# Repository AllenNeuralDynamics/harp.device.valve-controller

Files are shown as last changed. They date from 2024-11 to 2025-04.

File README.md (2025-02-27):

A Harp-compliant, 16-channel MOSFET Output board for valve control.

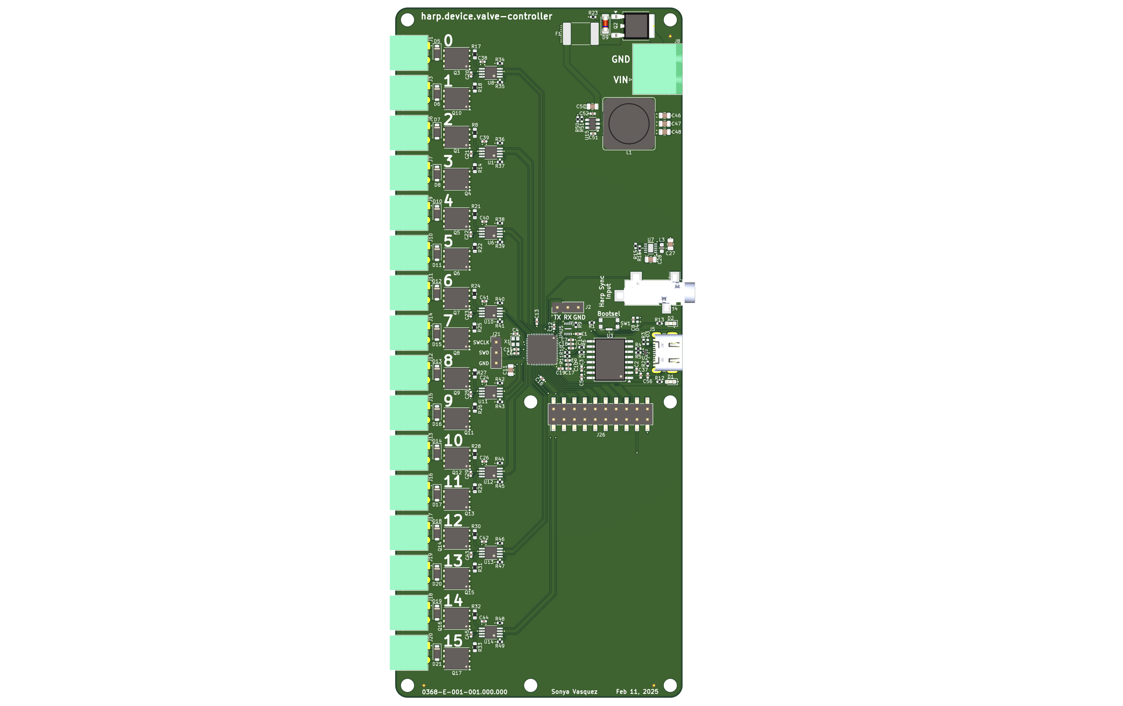
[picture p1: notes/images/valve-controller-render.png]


## Features
* Up to 5A total current consumption
* Up to 2A on any single output channel
* 8-GPIO expansion header

## Enclosure
See the companion [Onshape project](https://cad.onshape.com/documents/b68e9ca81d13baa37ddbb87a/w/239401edd39de6ea07d882fc/e/2e7e06ce5de5ab57a801ffd8) for the PCBA enclosure.

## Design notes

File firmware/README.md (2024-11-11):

## Setting up the Build Environment

### Install Submodules
This project uses the [Harp Core RP2040](https://github.com/AllenNeuralDynamics/harp.core.rp2040) library as a submodule.
Install it with:
````
git submodule update --init
````

### Install Pico SDK
This project uses the [Pico SDK](https://github.com/raspberrypi/pico-sdk/tree/master).
The SDK needs to be downloaded and installed to a known folder on your PC.
Note that the PICO SDK also contains submodules (including TinyUSB), so you must ensure that they are also fetched with:
````
git clone git clone git@github.com:raspberrypi/pico-sdk.git
git submodule update --init --recursive
````

### Point to Pico SDK
Recommended, but optional: define the `PICO_SDK_PATH` environment variable to point to the location where the pico-sdk was downloaded. i.e:
````
PICO_SDK_PATH=/home/username/projects/pico-sdk
````
On Linux, it may be preferrable to put this in your `.bashrc` file.

## Compiling the Firmware

### Without an IDE
From this directory, create a directory called build, enter it, and invoke cmake with:
````
mkdir build
cd build
cmake ..
````
If you did not define the `PICO_SDK_PATH` as an environment variable, you must pass it in here like so:
````
mkdir build
cd build
cmake -DPICO_SDK_PATH=/path/to/pico-sdk ..
````
After this point, you can invoke the auto-generated Makefile with `make`

## Flashing the Firmware
Press-and-hold the Pico's BOOTSEL button and power it up (i.e: plug it into usb).
At this point you do one of the following:
* drag-and-drop the created **\*.uf2** file into the mass storage device that appears on your pc.
* flash with [picotool](https://github.com/raspberrypi/picotool)

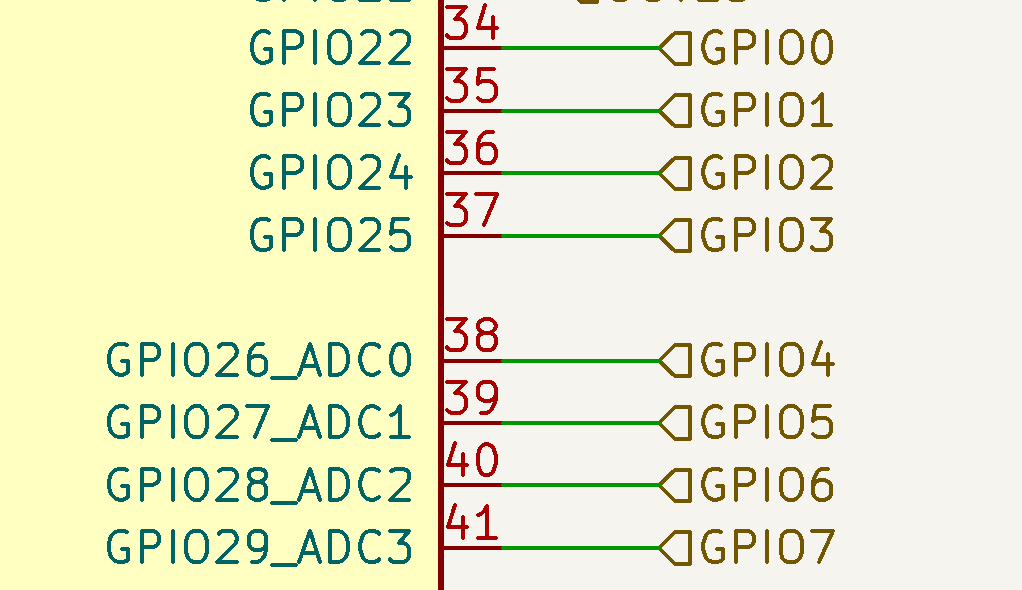
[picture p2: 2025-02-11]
notes/images/gpio-expansion-pinout.png

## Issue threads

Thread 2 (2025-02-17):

Hit-and-Hold Valve Control

Poofjunior, 2025-02-17:
Numerous valves cannot be energized and left on at their nominal voltage, or they risk burning up. The solution is a *hit-and-hold* strategy where the valve is initially energized at it's nominal voltage and then left energized at a reduced voltage that is just high enough to keep the valve energized, but low enough so as not to burn out the solenoid if left on continuously.

We can achieve a simple hit-and-hold strategy using PWM to modulate the output voltage and current sent to the valve and simple state machine to control hit-to-hold transition logic.

We will need hit-and-hold pwm control for all 16 valve outputs.

### References
* [Hit and Hold Driver Strategy from Lee Co](https://www.theleeco.com/support-resources/engineering-tools/electrical-engineering/drive-circuits/)

Poofjunior, 2025-02-21:
This is implemented in https://github.com/AllenNeuralDynamics/harp.device.valve-controller/pull/4

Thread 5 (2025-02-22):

AUX GPIO Event Trigger

Poofjunior, 2025-02-22:
The values configured as digital *inputs* need to be able to send Harp `EVENT` reply messages if their outputs rise, fall, or change.

We need to be able to configure which of the digital inputs will emit these messages, and on what condition they will emit. We can do this with 3 registers:
```cpp
{
    uint8_t AuxGPIOInputEvent;
    uint8_t AuxGPIORise;
    uint8_t AuxGPIOFall;
}
```

The `AuxGPIOInputEvent` will configure which GPIOs will emit a message, and the following two registers will configure what pin change (or both) will emit the EVENT.

These events should emit from the `AuxGPIOInputEvent` or `AuxGPIOState` register.

Poofjunior, 2025-02-24:
This is now implemented in https://github.com/AllenNeuralDynamics/harp.device.valve-controller/pull/4 but the final registers ended up being:

```cpp

    uint8_t AuxGPIOInputRiseEvent;
    uint8_t AuxGPIOInputFallEvent;
    uint8_t AuxGPIORisingInputs; // Raw state of which inputs rose (could be multiple)
    uint8_t AuxGPIOFallingInputs; // Raw state of which inputs fell (could be multiple

```

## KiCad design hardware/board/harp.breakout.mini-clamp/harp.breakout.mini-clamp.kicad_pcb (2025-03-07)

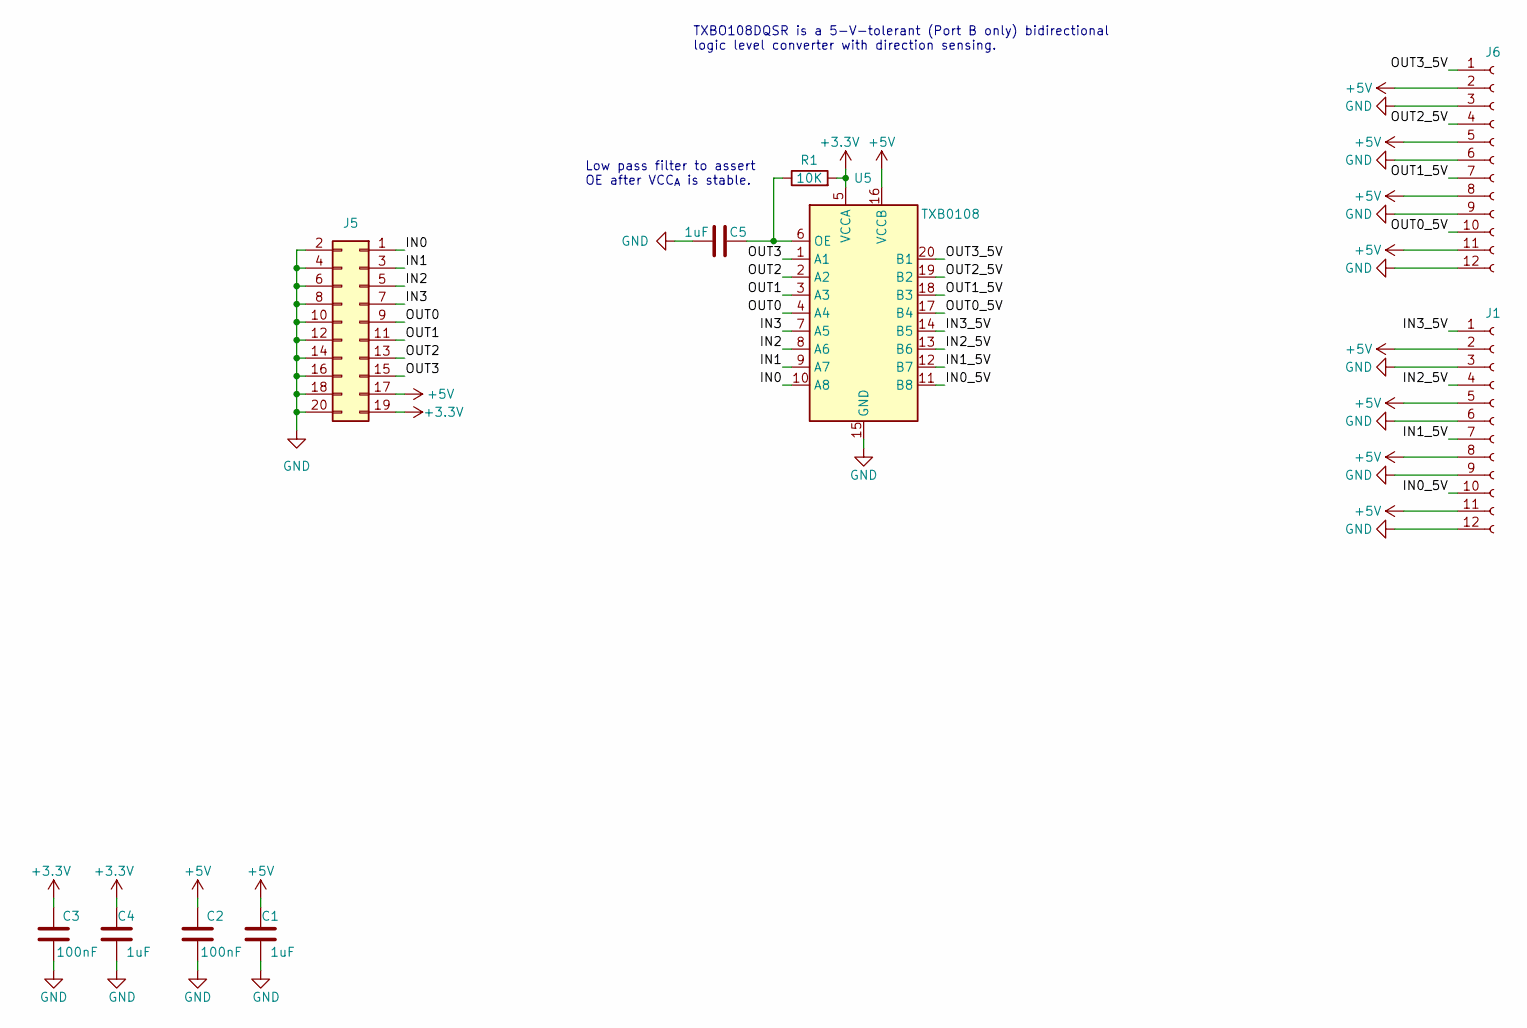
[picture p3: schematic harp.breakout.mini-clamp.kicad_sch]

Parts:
C1, C4, C5: 1uF; C_0402_1005Metric_Pad0.74x0.62mm_HandSolder; Rated Voltage 35V
C2, C3: 100nF; C_0402_1005Metric_Pad0.74x0.62mm_HandSolder; Rated Voltage 50V; Tolerance 10%
J1, J6: Conn_01x12_Socket; 3M_Mini-Clamp-Socket-37212-62M3-003PL-3x4_Vertical
J5: Conn_02x10_Odd_Even; PinSocket_2x10_P2.54mm_Vertical
R1: 10K; R_0402_1005Metric_Pad0.72x0.64mm_HandSolder
U5: TXB0108; TSSOP-20_4.4x6.5mm_P0.65mm

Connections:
+3.3V: C3.2, C4.1, J5.19, R1.2, U5.5 (VCCA)
+5V: C1.1, C2.2, J1.2, J1.5, J1.8, J1.11, J5.17, J6.2, J6.5, J6.8, J6.11, U5.16 (VCCB)
/IN0: J5.1, U5.10 (A8)
/IN0_5V: J1.10, U5.11 (B8)
/IN1: J5.3, U5.9 (A7)
/IN1_5V: J1.7, U5.12 (B7)
/IN2: J5.5, U5.8 (A6)
/IN2_5V: J1.4, U5.13 (B6)
/IN3: J5.7, U5.7 (A5)
/IN3_5V: J1.1, U5.14 (B5)
/OUT0: J5.9, U5.4 (A4)
/OUT0_5V: J6.10, U5.17 (B4)
/OUT1: J5.11, U5.3 (A3)
/OUT1_5V: J6.7, U5.18 (B3)
/OUT2: J5.13, U5.2 (A2)
/OUT2_5V: J6.4, U5.19 (B2)
/OUT3: J5.15, U5.1 (A1)
/OUT3_5V: J6.1, U5.20 (B1)
GND: C1.2, C2.1, C3.1, C4.2, C5.2, J1.3, J1.6, J1.9, J1.12, J5.2, J5.4, J5.6, J5.8, J5.10, J5.12, J5.14, J5.16, J5.18, J5.20, J6.3, J6.6, J6.9, J6.12, U5.15 (GND)
unnamed: C5.1, R1.1, U5.6 (OE)

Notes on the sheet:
Low pass filter to assert OE after VCC_{A} is stable.
TXBO108DQSR is a 5-V-tolerant (Port B only) bidirectional logic level converter with direction sensing.

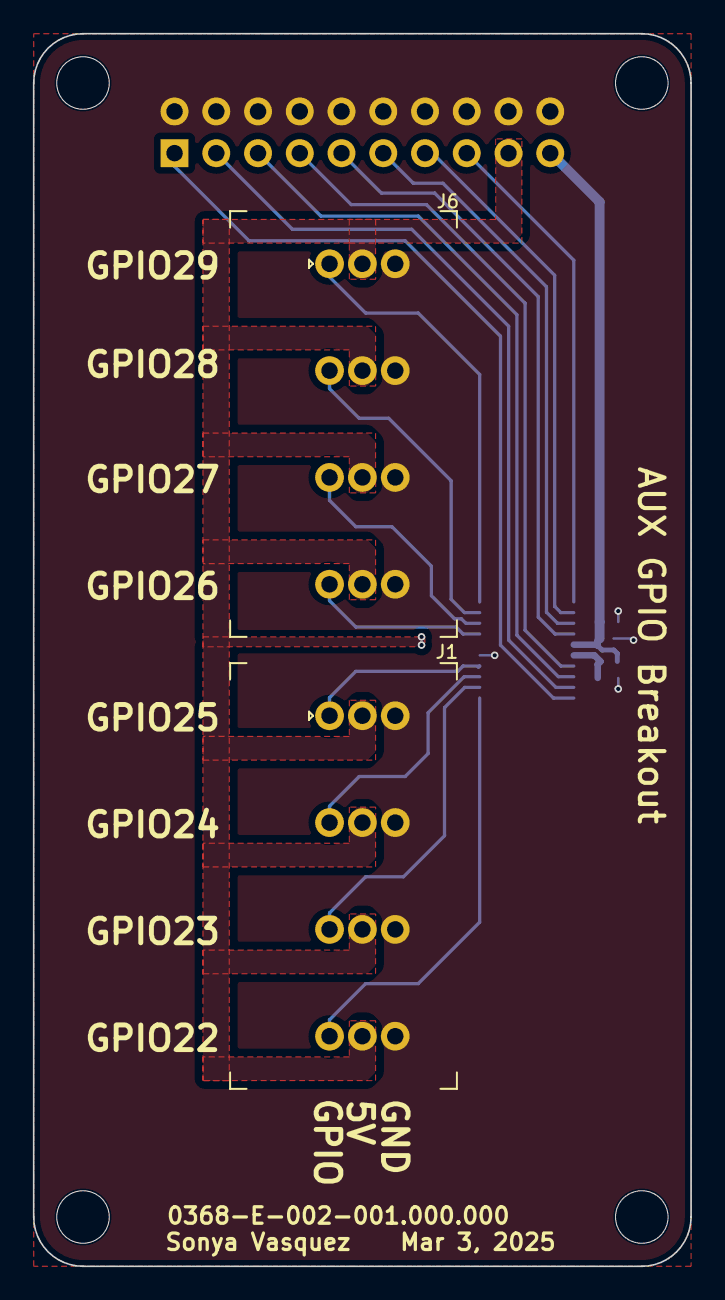
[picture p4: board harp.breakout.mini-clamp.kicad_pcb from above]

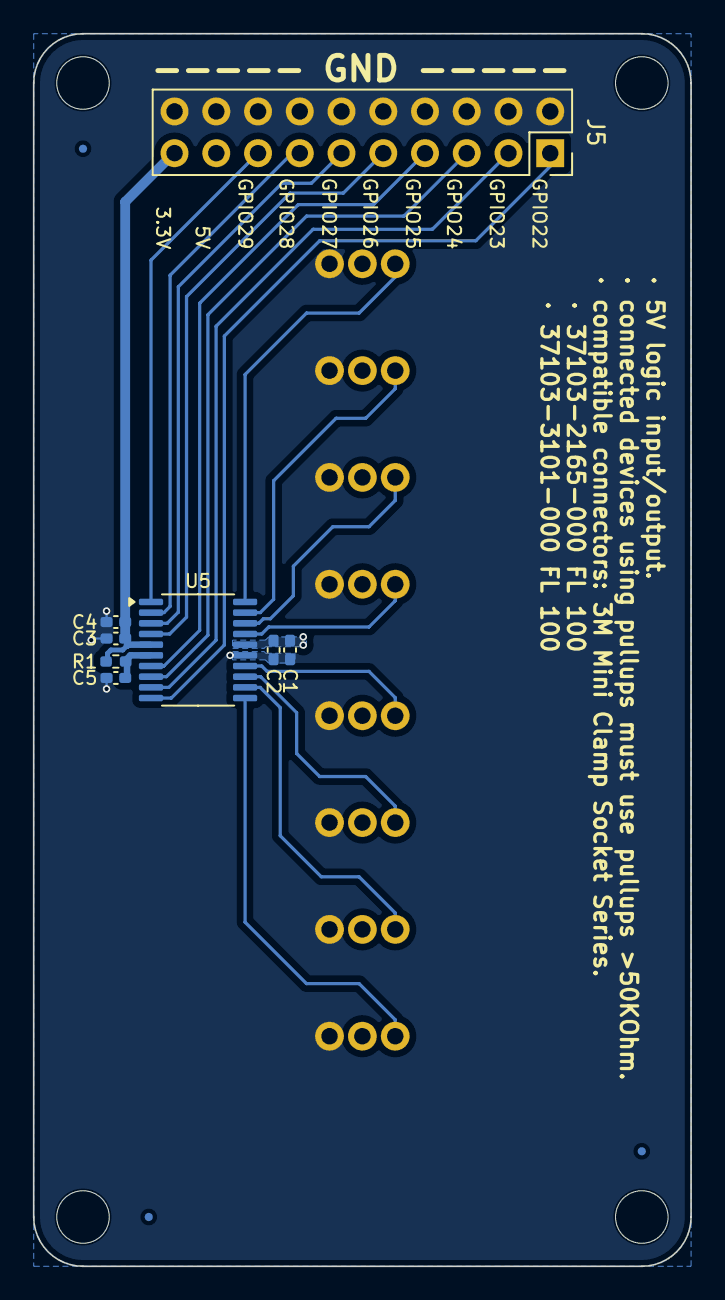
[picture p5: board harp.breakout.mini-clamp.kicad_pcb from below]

Board: 2 copper layers, 40.0 x 75.0 mm, 13 parts (11 on the bottom side), 20 nets.

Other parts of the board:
FID2, FID2#2, FID2#3: Fiducial; Fiducial_0.5mm_Mask1mm

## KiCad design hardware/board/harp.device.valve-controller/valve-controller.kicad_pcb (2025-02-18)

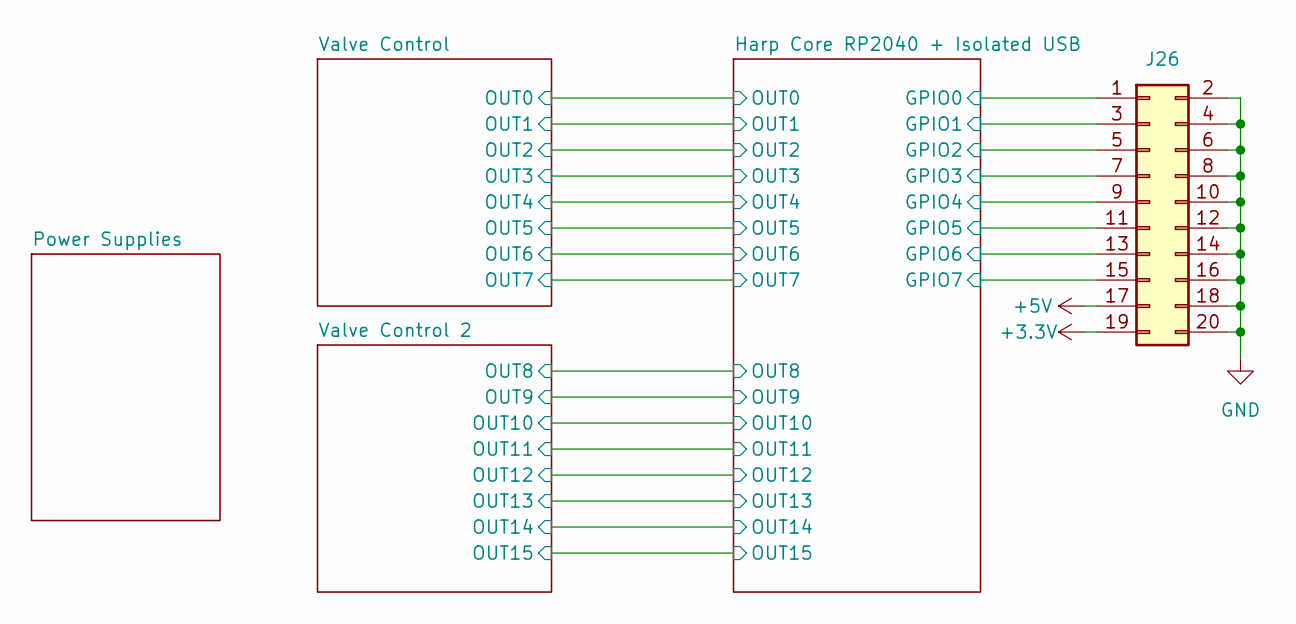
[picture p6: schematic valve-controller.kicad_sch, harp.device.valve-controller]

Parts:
J26: Conn_02x10_Odd_Even; PinHeader_2x10_P2.54mm_Vertical_SMD

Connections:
+3.3V: J26.19; also elsewhere on the board
+5V: J26.17; also elsewhere on the board
/Harp Core RP2040 + Isolated USB/GPIO0: J26.1; also elsewhere on the board
/Harp Core RP2040 + Isolated USB/GPIO1: J26.3; also elsewhere on the board
/Harp Core RP2040 + Isolated USB/GPIO2: J26.5; also elsewhere on the board
/Harp Core RP2040 + Isolated USB/GPIO3: J26.7; also elsewhere on the board
/Harp Core RP2040 + Isolated USB/GPIO4: J26.9; also elsewhere on the board
/Harp Core RP2040 + Isolated USB/GPIO5: J26.11; also elsewhere on the board
/Harp Core RP2040 + Isolated USB/GPIO6: J26.13; also elsewhere on the board
/Harp Core RP2040 + Isolated USB/GPIO7: J26.15; also elsewhere on the board
GND: J26.2, J26.4, J26.6, J26.8, J26.10, J26.12, J26.14, J26.16, J26.18, J26.20; also elsewhere on the board

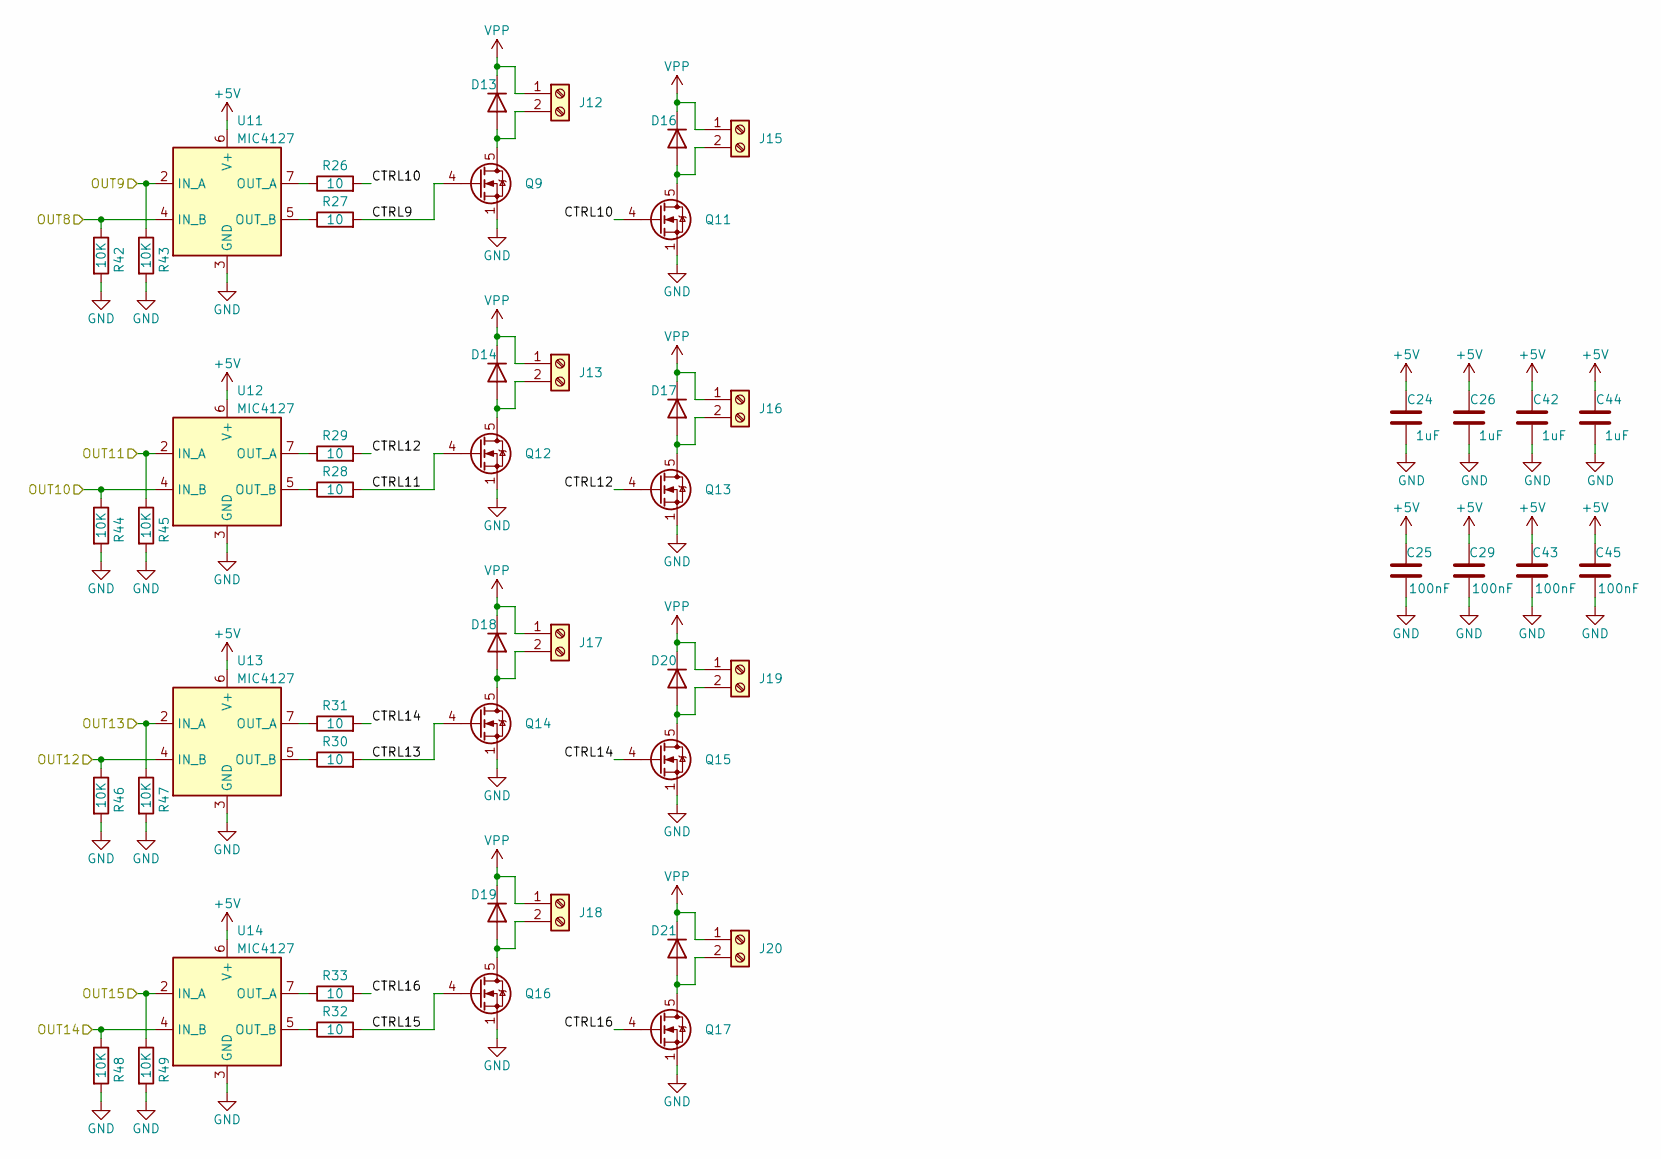
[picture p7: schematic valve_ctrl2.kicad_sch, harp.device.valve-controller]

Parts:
C24, C26, C42, C44: 1uF; C_0402_1005Metric; Rated Voltage 35V
C25, C29, C43, C45: 100nF; C_0402_1005Metric; Rated Voltage 50V; Tolerance 10%
D13, D14, D16, D17, D18, D19, D20, D21: 1N4007FL; D_SOD-123F
J12, J13, J15, J16, J17, J18, J19, J20: Screw_Terminal_01x02; PhoenixContact_MC_1,5_2-G-3.5_1x02_P3.50mm_Horizontal
Q9, Q11, Q12, Q13, Q14, Q15, Q16, Q17: CSD17570Q5B; TDSON-8-1
R26, R27, R28, R29, R30, R31, R32, R33: 10; R_0603_1608Metric; Tolerance 1%
R42, R43, R44, R45, R46, R47, R48, R49: 10K; R_0402_1005Metric
U11, U12, U13, U14: MIC4127; MSOP-8-1EP_3x3mm_P0.65mm_EP1.5x1.8mm

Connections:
+5V: C24.1, C25.2, C26.1, C29.2, C42.1, C43.2, C44.1, C45.2, U11.6 (V+), U12.6 (V+), U13.6 (V+), U14.6 (V+); also elsewhere on the board
/Harp Core RP2040 + Isolated USB/OUT8: R42.1, U11.4 (IN_B); also elsewhere on the board
/Harp Core RP2040 + Isolated USB/OUT9: R43.1, U11.2 (IN_A); also elsewhere on the board
/Harp Core RP2040 + Isolated USB/OUT10: R44.1, U12.4 (IN_B); also elsewhere on the board
/Harp Core RP2040 + Isolated USB/OUT11: R45.1, U12.2 (IN_A); also elsewhere on the board
/Harp Core RP2040 + Isolated USB/OUT12: R46.1, U13.4 (IN_B); also elsewhere on the board
/Harp Core RP2040 + Isolated USB/OUT13: R47.1, U13.2 (IN_A); also elsewhere on the board
/Harp Core RP2040 + Isolated USB/OUT14: R48.1, U14.4 (IN_B); also elsewhere on the board
/Harp Core RP2040 + Isolated USB/OUT15: R49.1, U14.2 (IN_A); also elsewhere on the board
/Valve Control 2/CTRL9: Q9.4 (G), R27.2
/Valve Control 2/CTRL10: Q11.4 (G), R26.2
/Valve Control 2/CTRL11: Q12.4 (G), R28.2
/Valve Control 2/CTRL12: Q13.4 (G), R29.2
/Valve Control 2/CTRL13: Q14.4 (G), R30.2
/Valve Control 2/CTRL14: Q15.4 (G), R31.2
/Valve Control 2/CTRL15: Q16.4 (G), R32.2
/Valve Control 2/CTRL16: Q17.4 (G), R33.2
GND: C24.2, C25.1, C26.2, C29.1, C42.2, C43.1, C44.2, C45.1, Q9.1 (S), Q9.2 (S), Q9.3 (S), Q11.1 (S), Q11.2 (S), Q11.3 (S), Q12.1 (S), Q12.2 (S), Q12.3 (S), Q13.1 (S), Q13.2 (S), Q13.3 (S), Q14.1 (S), Q14.2 (S), Q14.3 (S), Q15.1 (S), Q15.2 (S), Q15.3 (S), Q16.1 (S), Q16.2 (S), Q16.3 (S), Q17.1 (S), Q17.2 (S), Q17.3 (S), R42.2, R43.2, R44.2, R45.2, R46.2, R47.2, R48.2, R49.2, U11.3 (GND), U11.9 (GND), U12.3 (GND), U12.9 (GND), U13.3 (GND), U13.9 (GND), U14.3 (GND), U14.9 (GND); also elsewhere on the board
unnamed: D13.2 (A), J12.2, Q9.5 (D)
unnamed: D14.2 (A), J13.2, Q12.5 (D)
unnamed: D16.2 (A), J15.2, Q11.5 (D)
unnamed: D17.2 (A), J16.2, Q13.5 (D)
unnamed: D18.2 (A), J17.2, Q14.5 (D)
unnamed: D19.2 (A), J18.2, Q16.5 (D)
unnamed: D20.2 (A), J19.2, Q15.5 (D)
unnamed: D21.2 (A), J20.2, Q17.5 (D)
unnamed: R26.1, U11.7 (OUT_A)
unnamed: R27.1, U11.5 (OUT_B)
unnamed: R29.1, U12.7 (OUT_A)
unnamed: R28.1, U12.5 (OUT_B)
unnamed: R31.1, U13.7 (OUT_A)
unnamed: R30.1, U13.5 (OUT_B)
unnamed: R33.1, U14.7 (OUT_A)
unnamed: R32.1, U14.5 (OUT_B)
VPP: D13.1 (K), D14.1 (K), D16.1 (K), D17.1 (K), D18.1 (K), D19.1 (K), D20.1 (K), D21.1 (K), J12.1, J13.1, J15.1, J16.1, J17.1, J18.1, J19.1, J20.1; also elsewhere on the board

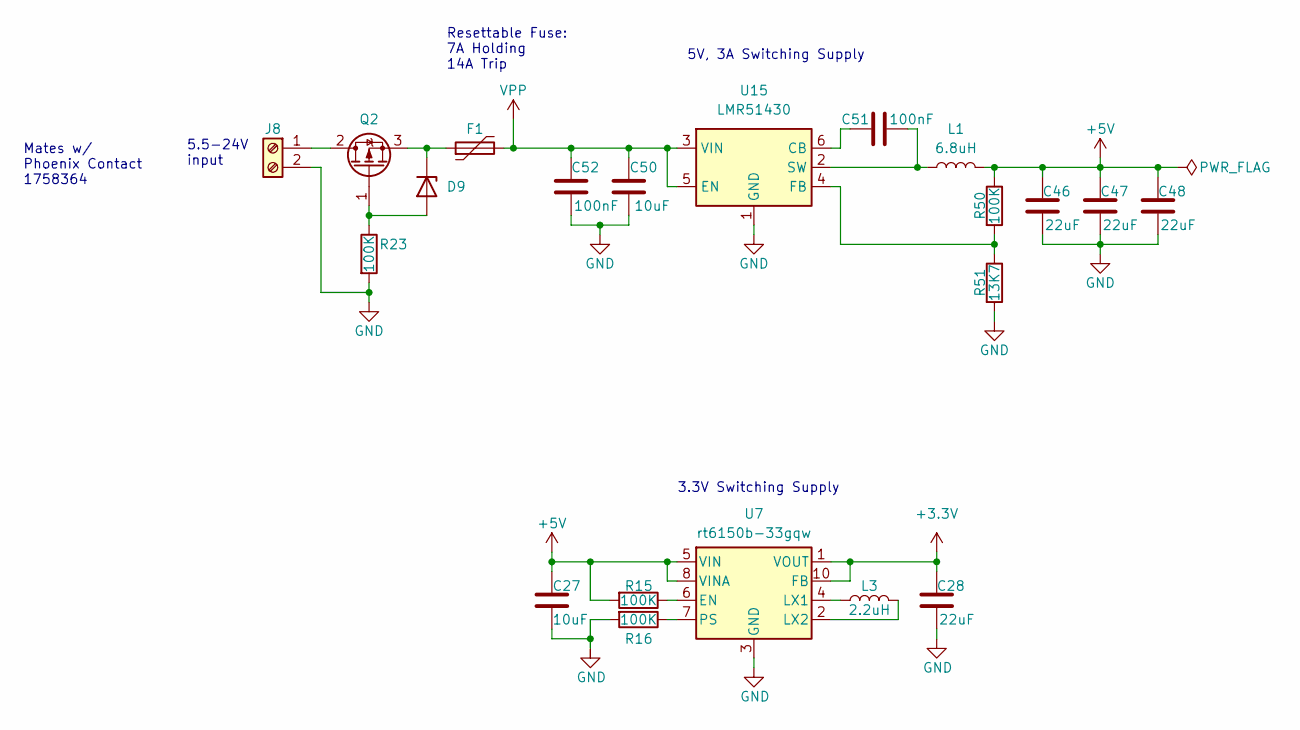
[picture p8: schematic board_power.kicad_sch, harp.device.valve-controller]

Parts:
C27, C50: 10uF; C_0805_2012Metric
C28, C46, C47, C48: 22uF; C_0805_2012Metric; Rated Voltage 10V
C51, C52: 100nF; C_0402_1005Metric; Rated Voltage 50V; Tolerance 10%
D9: BZV55B15; D_MiniMELF
F1: Polyfuse; Fuse_2920_7451Metric
J8: Screw_Terminal_01x02; PhoenixContact_MSTBA_2,5_2-G-5,08_1x02_P5.08mm_Horizontal
L1: 6.8uH; L_Bourns_SRR1260
L3: 2.2uH; L_0603_1608Metric
Q2: GSFD4005; TO-252-2
R15, R16, R23, R50: 100K; R_0402_1005Metric; Tolerance 1%
R51: 13K7; R_0402_1005Metric; Tolerance 1%
U7: rt6150b-33gqw; WDFN-10-1EP_2.5x2.5mm_P0.5_EP1.25x2.1mm
U15: LMR51430; SOT-23-6

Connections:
+3.3V: C28.2, U7.1 (VOUT), U7.10 (FB); also elsewhere on the board
+5V: C27.1, C46.2, C47.2, C48.2, L1.2, R15.2, R50.1, U7.5 (VIN), U7.8 (VINA); also elsewhere on the board
GND: C27.2, C28.1, C46.1, C47.1, C48.1, C50.2, C52.1, J8.2, R16.2, R23.2, R51.2, U7.3 (GND), U7.9 (GND), U7.11 (GND), U15.1 (GND); also elsewhere on the board
unnamed: D9.2 (A), Q2.1 (G), R23.1
unnamed: D9.1 (K), F1.1, Q2.3 (S)
unnamed: J8.1, Q2.2 (D)
unnamed: R15.1, U7.6 (EN)
unnamed: L3.1, U7.4 (LX1)
unnamed: L3.2, U7.2 (LX2)
unnamed: R16.1, U7.7 (PS)
unnamed: C51.2, U15.6 (CB)
unnamed: R50.2, R51.1, U15.4 (FB)
unnamed: C51.1, L1.1, U15.2 (SW)
VPP: C50.1, C52.2, F1.2, U15.3 (VIN), U15.5 (EN); also elsewhere on the board

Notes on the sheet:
5.5-24V input
3.3V Switching Supply
Mates w/ Phoenix Contact 1758364
5V, 3A Switching Supply
Resettable Fuse: 7A Holding 14A Trip

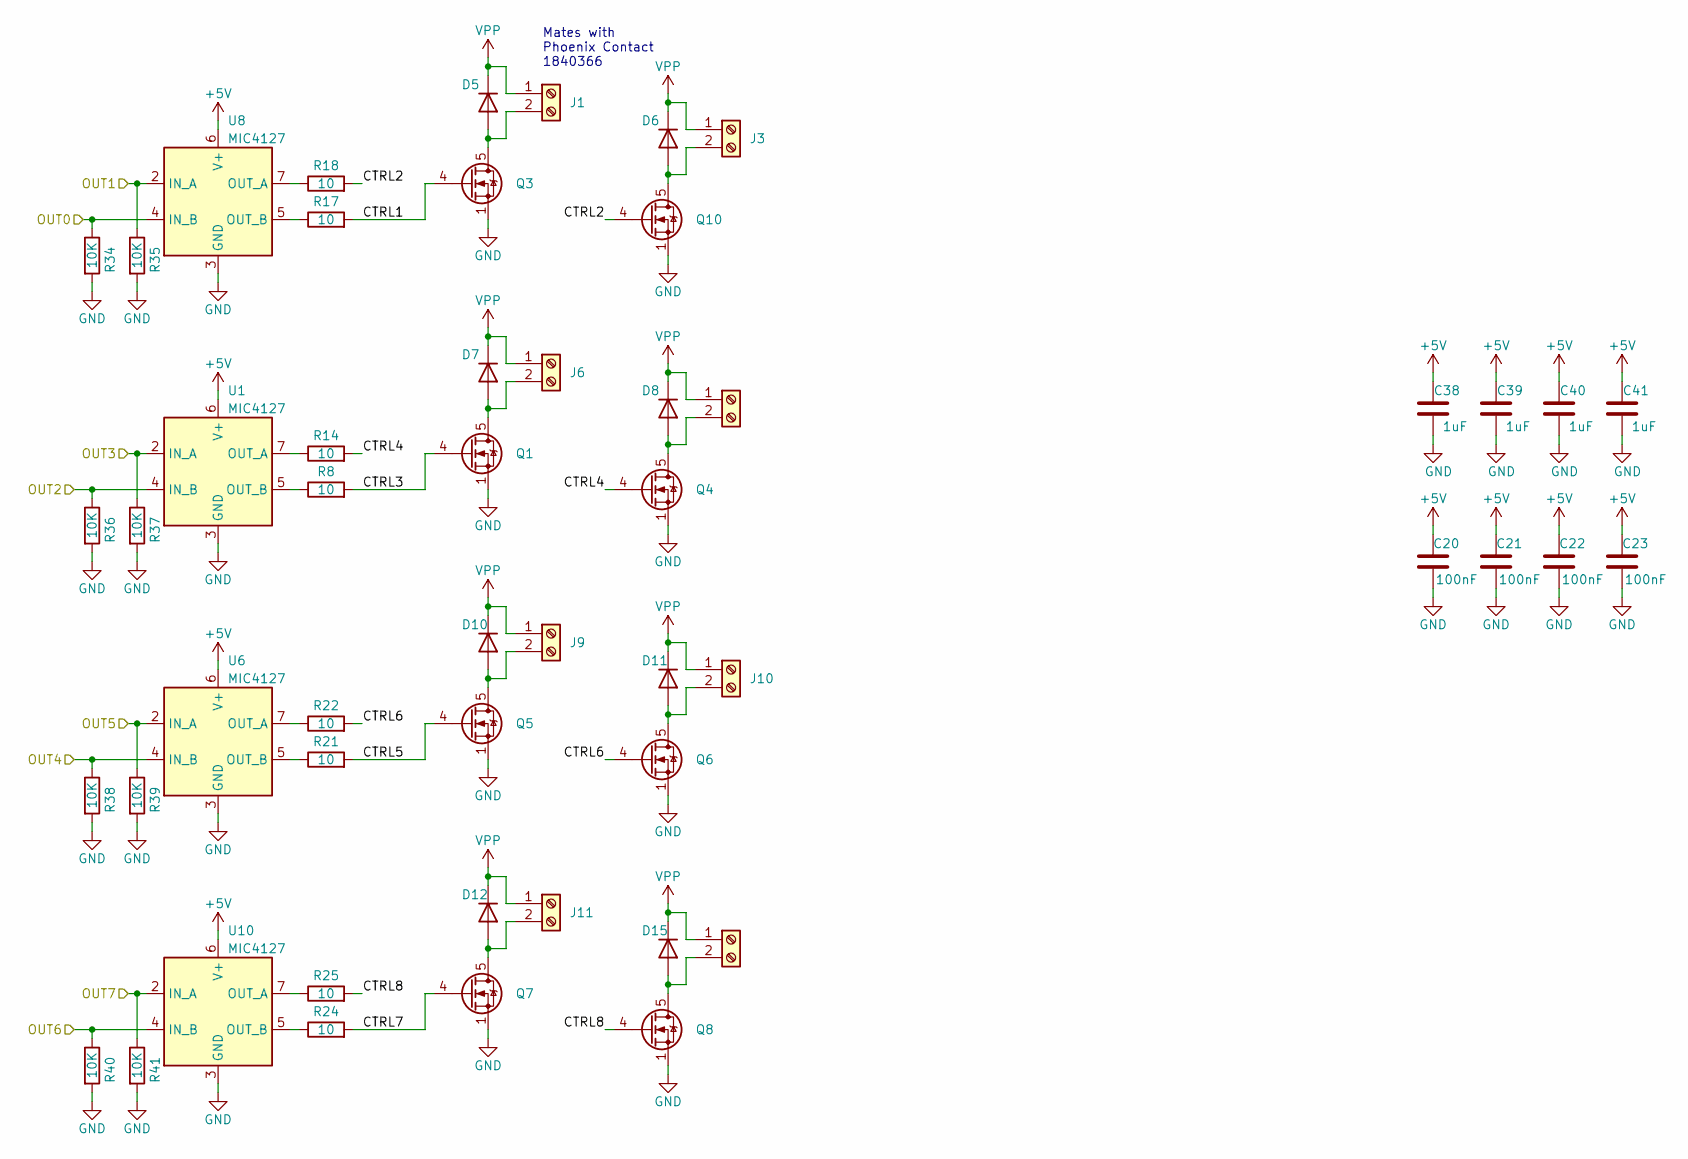
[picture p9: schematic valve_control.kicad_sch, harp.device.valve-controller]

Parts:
C20, C21, C22, C23: 100nF; C_0402_1005Metric; Rated Voltage 50V; Tolerance 10%
C38, C39, C40, C41: 1uF; C_0402_1005Metric; Rated Voltage 35V
D5, D6, D7, D8, D10, D11, D12, D15: 1N4007FL; D_SOD-123F
J1, J3, J6, J7, J9, J10, J11, J14: Screw_Terminal_01x02; PhoenixContact_MC_1,5_2-G-3.5_1x02_P3.50mm_Horizontal
Q1, Q3, Q4, Q5, Q6, Q7, Q8, Q10: CSD17570Q5B; TDSON-8-1
R8, R14, R17, R18, R21, R22, R24, R25: 10; R_0603_1608Metric; Tolerance 1%
R34, R35, R36, R37, R38, R39, R40, R41: 10K; R_0402_1005Metric
U1, U6, U8, U10: MIC4127; MSOP-8-1EP_3x3mm_P0.65mm_EP1.5x1.8mm

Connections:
+5V: C20.2, C21.2, C22.2, C23.2, C38.1, C39.1, C40.1, C41.1, U1.6 (V+), U6.6 (V+), U8.6 (V+), U10.6 (V+); also elsewhere on the board
/Harp Core RP2040 + Isolated USB/OUT0: R34.1, U8.4 (IN_B); also elsewhere on the board
/Harp Core RP2040 + Isolated USB/OUT1: R35.1, U8.2 (IN_A); also elsewhere on the board
/Harp Core RP2040 + Isolated USB/OUT2: R36.1, U1.4 (IN_B); also elsewhere on the board
/Harp Core RP2040 + Isolated USB/OUT3: R37.1, U1.2 (IN_A); also elsewhere on the board
/Harp Core RP2040 + Isolated USB/OUT4: R38.1, U6.4 (IN_B); also elsewhere on the board
/Harp Core RP2040 + Isolated USB/OUT5: R39.1, U6.2 (IN_A); also elsewhere on the board
/Harp Core RP2040 + Isolated USB/OUT6: R40.1, U10.4 (IN_B); also elsewhere on the board
/Harp Core RP2040 + Isolated USB/OUT7: R41.1, U10.2 (IN_A); also elsewhere on the board
/Valve Control/CTRL1: Q3.4 (G), R17.2
/Valve Control/CTRL2: Q10.4 (G), R18.2
/Valve Control/CTRL3: Q1.4 (G), R8.2
/Valve Control/CTRL4: Q4.4 (G), R14.2
/Valve Control/CTRL5: Q5.4 (G), R21.2
/Valve Control/CTRL6: Q6.4 (G), R22.2
/Valve Control/CTRL7: Q7.4 (G), R24.2
/Valve Control/CTRL8: Q8.4 (G), R25.2
GND: C20.1, C21.1, C22.1, C23.1, C38.2, C39.2, C40.2, C41.2, Q1.1 (S), Q1.2 (S), Q1.3 (S), Q3.1 (S), Q3.2 (S), Q3.3 (S), Q4.1 (S), Q4.2 (S), Q4.3 (S), Q5.1 (S), Q5.2 (S), Q5.3 (S), Q6.1 (S), Q6.2 (S), Q6.3 (S), Q7.1 (S), Q7.2 (S), Q7.3 (S), Q8.1 (S), Q8.2 (S), Q8.3 (S), Q10.1 (S), Q10.2 (S), Q10.3 (S), R34.2, R35.2, R36.2, R37.2, R38.2, R39.2, R40.2, R41.2, U1.3 (GND), U1.9 (GND), U6.3 (GND), U6.9 (GND), U8.3 (GND), U8.9 (GND), U10.3 (GND), U10.9 (GND); also elsewhere on the board
unnamed: D5.2 (A), J1.2, Q3.5 (D)
unnamed: D6.2 (A), J3.2, Q10.5 (D)
unnamed: D7.2 (A), J6.2, Q1.5 (D)
unnamed: D8.2 (A), J7.2, Q4.5 (D)
unnamed: D10.2 (A), J9.2, Q5.5 (D)
unnamed: D11.2 (A), J10.2, Q6.5 (D)
unnamed: D12.2 (A), J11.2, Q7.5 (D)
unnamed: D15.2 (A), J14.2, Q8.5 (D)
unnamed: R14.1, U1.7 (OUT_A)
unnamed: R8.1, U1.5 (OUT_B)
unnamed: R22.1, U6.7 (OUT_A)
unnamed: R21.1, U6.5 (OUT_B)
unnamed: R18.1, U8.7 (OUT_A)
unnamed: R17.1, U8.5 (OUT_B)
unnamed: R25.1, U10.7 (OUT_A)
unnamed: R24.1, U10.5 (OUT_B)
VPP: D5.1 (K), D6.1 (K), D7.1 (K), D8.1 (K), D10.1 (K), D11.1 (K), D12.1 (K), D15.1 (K), J1.1, J3.1, J6.1, J7.1, J9.1, J10.1, J11.1, J14.1; also elsewhere on the board

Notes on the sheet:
Mates with Phoenix Contact 1840366

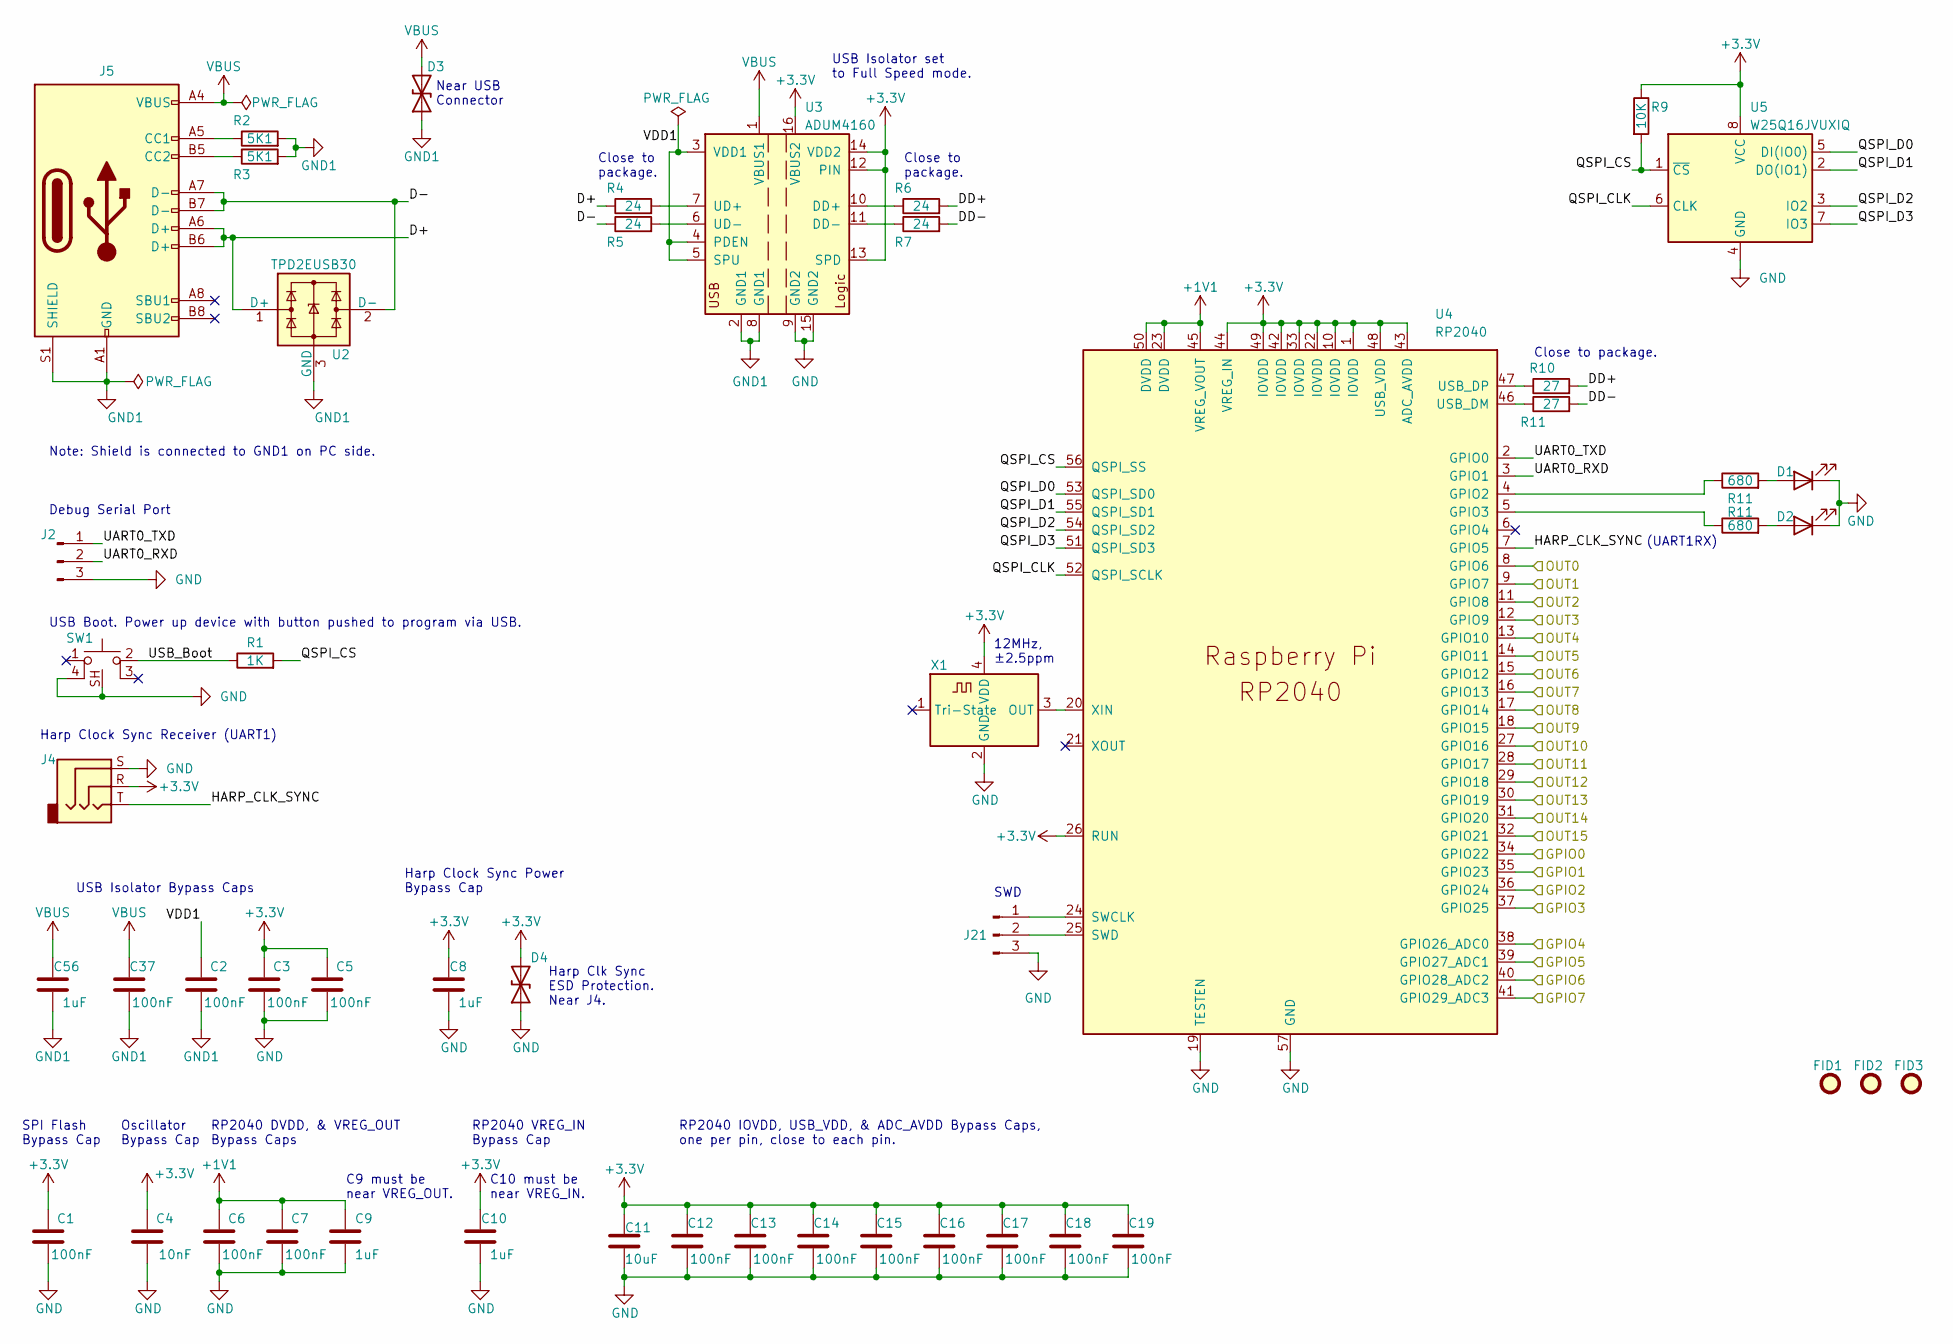
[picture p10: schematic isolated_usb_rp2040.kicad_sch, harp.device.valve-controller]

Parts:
C1, C2, C3, C5, C6, C7, C12, C13, C14, C15, C16, C17, C18, C19, C37: 100nF; C_0402_1005Metric; Rated Voltage 50V; Tolerance 10%
C4: 10nF; C_0402_1005Metric; Rated Voltage 25V; Tolerance 10%
C8, C9, C10, C56: 1uF; C_0402_1005Metric; Rated Voltage 35V
C11: 10uF; C_0805_2012Metric
D1, D2: LED; LED_0603_1608Metric_Pad1.05x0.95mm_HandSolder
D3, D4: D_TVS; D_0402_1005Metric
FID1, FID2, FID3: Fiducial; Fiducial_0.5mm_Mask1mm
J2, J21: Conn_01x03_Male; PinHeader_1x03_P2.54mm_Vertical
J4: AudioJack3; Jack_3.5mm_CUI_SJ-3524-SMT_Horizontal
J5: USB_C_Receptacle_USB2.0; USB_C_Receptacle_JAE_DX07S016JA1R1500
R1: 1K; R_0402_1005Metric; Tolerance 1%
R2, R3: 5K1; R_0402_1005Metric; Tolerance 1%
R4, R5, R6, R7: 24; R_0402_1005Metric; Tolerance 1%
R9: 10K; R_0402_1005Metric
R10, R11: 27; R_0402_1005Metric; Tolerance 1%
SW1: SW_Push_1P1T-SH_NO_Vertical_Wuerth_WS-TASV
U2: TPD2EUSB30; Texas_DRT-3
U3: ADUM4160; SOIC-16W_7.5x10.3mm_P1.27mm
U4: RP2040; RP2040-QFN-56
U5: W25Q16JVUXIQ; Winbond-8USON-2x3mm
X1: ECS-TXO-2016; Crystal_SMD_2016-4Pin_2.0x1.6mm; Tolerance ±2.5ppm

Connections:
+1V1: C6.2, C7.2, C9.1, U4.23 (DVDD), U4.45 (VREG_VOUT), U4.50 (DVDD)
+3.3V: C1.2, C3.2, C4.2, C5.2, C8.1, C10.1, C11.1, C12.2, C13.2, C14.2, C15.2, C16.2, C17.2, C18.2, C19.2, D4.2 (A2), J4.R, R9.1, U3.12 (PIN), U3.13 (SPD), U3.14 (VDD2), U3.16 (VBUS2), U4.1 (IOVDD), U4.10 (IOVDD), U4.22 (IOVDD), U4.26 (RUN), U4.33 (IOVDD), U4.42 (IOVDD), U4.43 (ADC_AVDD), U4.44 (VREG_IN), U4.48 (USB_VDD), U4.49 (IOVDD), U5.8 (VCC), X1.4 (VDD); also elsewhere on the board
/Harp Core RP2040 + Isolated USB/D+: J5.A6 (D+), J5.B6 (D+), R4.1, U2.1 (D+)
/Harp Core RP2040 + Isolated USB/D-: J5.A7 (D-), J5.B7 (D-), R5.1, U2.2 (D-)
/Harp Core RP2040 + Isolated USB/DD+: R6.2, R10.2
/Harp Core RP2040 + Isolated USB/GPIO0: U4.34 (GPIO22); also elsewhere on the board
/Harp Core RP2040 + Isolated USB/GPIO1: U4.35 (GPIO23); also elsewhere on the board
/Harp Core RP2040 + Isolated USB/GPIO2: U4.36 (GPIO24); also elsewhere on the board
/Harp Core RP2040 + Isolated USB/GPIO3: U4.37 (GPIO25); also elsewhere on the board
/Harp Core RP2040 + Isolated USB/GPIO4: U4.38 (GPIO26_ADC0); also elsewhere on the board
/Harp Core RP2040 + Isolated USB/GPIO5: U4.39 (GPIO27_ADC1); also elsewhere on the board
/Harp Core RP2040 + Isolated USB/GPIO6: U4.40 (GPIO28_ADC2); also elsewhere on the board
/Harp Core RP2040 + Isolated USB/GPIO7: U4.41 (GPIO29_ADC3); also elsewhere on the board
/Harp Core RP2040 + Isolated USB/HARP_CLK_SYNC: J4.T, U4.7 (GPIO5)
/Harp Core RP2040 + Isolated USB/OUT0: U4.8 (GPIO6); also elsewhere on the board
/Harp Core RP2040 + Isolated USB/OUT1: U4.9 (GPIO7); also elsewhere on the board
/Harp Core RP2040 + Isolated USB/OUT2: U4.11 (GPIO8); also elsewhere on the board
/Harp Core RP2040 + Isolated USB/OUT3: U4.12 (GPIO9); also elsewhere on the board
/Harp Core RP2040 + Isolated USB/OUT4: U4.13 (GPIO10); also elsewhere on the board
/Harp Core RP2040 + Isolated USB/OUT5: U4.14 (GPIO11); also elsewhere on the board
/Harp Core RP2040 + Isolated USB/OUT6: U4.15 (GPIO12); also elsewhere on the board
/Harp Core RP2040 + Isolated USB/OUT7: U4.16 (GPIO13); also elsewhere on the board
/Harp Core RP2040 + Isolated USB/OUT8: U4.17 (GPIO14); also elsewhere on the board
/Harp Core RP2040 + Isolated USB/OUT9: U4.18 (GPIO15); also elsewhere on the board
/Harp Core RP2040 + Isolated USB/OUT10: U4.27 (GPIO16); also elsewhere on the board
/Harp Core RP2040 + Isolated USB/OUT11: U4.28 (GPIO17); also elsewhere on the board
/Harp Core RP2040 + Isolated USB/OUT12: U4.29 (GPIO18); also elsewhere on the board
/Harp Core RP2040 + Isolated USB/OUT13: U4.30 (GPIO19); also elsewhere on the board
/Harp Core RP2040 + Isolated USB/OUT14: U4.31 (GPIO20); also elsewhere on the board
/Harp Core RP2040 + Isolated USB/OUT15: U4.32 (GPIO21); also elsewhere on the board
/Harp Core RP2040 + Isolated USB/QSPI_CLK: U4.52 (QSPI_SCLK), U5.6 (CLK)
/Harp Core RP2040 + Isolated USB/QSPI_CS: R1.2, R9.2, U4.56 (QSPI_SS), U5.1 (~CS)
/Harp Core RP2040 + Isolated USB/QSPI_D0: U4.53 (QSPI_SD0), U5.5 (DI(IO0))
/Harp Core RP2040 + Isolated USB/QSPI_D1: U4.55 (QSPI_SD1), U5.2 (DO(IO1))
/Harp Core RP2040 + Isolated USB/QSPI_D2: U4.54 (QSPI_SD2), U5.3 (IO2)
/Harp Core RP2040 + Isolated USB/QSPI_D3: U4.51 (QSPI_SD3), U5.7 (IO3)
/Harp Core RP2040 + Isolated USB/UART0_RXD: J2.2, U4.3 (GPIO1)
/Harp Core RP2040 + Isolated USB/UART0_TXD: J2.1, U4.2 (GPIO0)
/Harp Core RP2040 + Isolated USB/USB_Boot: R1.1, SW1.2
/Harp Core RP2040 + Isolated USB/VDD1: C2.2, U3.3 (VDD1), U3.4 (PDEN), U3.5 (SPU)
GND: C1.1, C3.1, C4.1, C5.1, C6.1, C7.1, C8.2, C9.2, C10.2, C11.2, C12.1, C13.1, C14.1, C15.1, C16.1, C17.1, C18.1, C19.1, D1.1 (K), D2.1 (K), D4.1 (A1), J2.3, J4.S, J21.3, SW1.4, SW1.SH, U3.9 (GND2), U3.15 (GND2), U4.19 (TESTEN), U4.57 (GND), U5.4 (GND), X1.2 (GND); also elsewhere on the board
GND1: C2.1, C37.1, C56.2, D3.1 (A1), J5.A1 (GND), J5.A12 (GND), J5.B1 (GND), J5.B12 (GND), J5.S1 (SHIELD), R2.2, R3.2, U2.3 (GND), U3.2 (GND1), U3.8 (GND1)
unnamed: J5.A5 (CC1), R2.1
unnamed: J5.B5 (CC2), R3.1
unnamed: J21.1, U4.24 (SWCLK)
unnamed: J21.2, U4.25 (SWD)
unnamed: R6.1, U3.10 (DD+)
unnamed: R7.1, U3.11 (DD-)
unnamed: R4.2, U3.7 (UD+)
unnamed: R5.2, U3.6 (UD-)
unnamed: R10.1, U4.47 (USB_DP)
unnamed: U4.20 (XIN), X1.3 (OUT)
VBUS: C37.2, C56.1, D3.2 (A2), J5.A4 (VBUS), J5.A9 (VBUS), J5.B4 (VBUS), J5.B9 (VBUS), U3.1 (VBUS1)

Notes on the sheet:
Close to package.
SWD
Near USB Connector
Close to package.
(UART1RX)
Harp Clk Sync ESD Protection. Near J4.
RP2040 VREG_IN Bypass Cap
Oscillator Bypass Cap
Harp Clock Sync Power Bypass Cap
C10 must be near VREG_IN.
RP2040 DVDD, & VREG_OUT Bypass Caps
Debug Serial Port
USB Boot. Power up device with button pushed to program via USB.
C9 must be near VREG_OUT.
Harp Clock Sync Receiver (UART1)
12MHz, ±2.5ppm
Note: Shield is connected to GND1 on PC side.
RP2040 IOVDD, USB_VDD, & ADC_AVDD Bypass Caps, one per pin, close to each pin.
USB Isolator Bypass Caps
SPI Flash Bypass Cap
USB Isolator set to Full Speed mode.

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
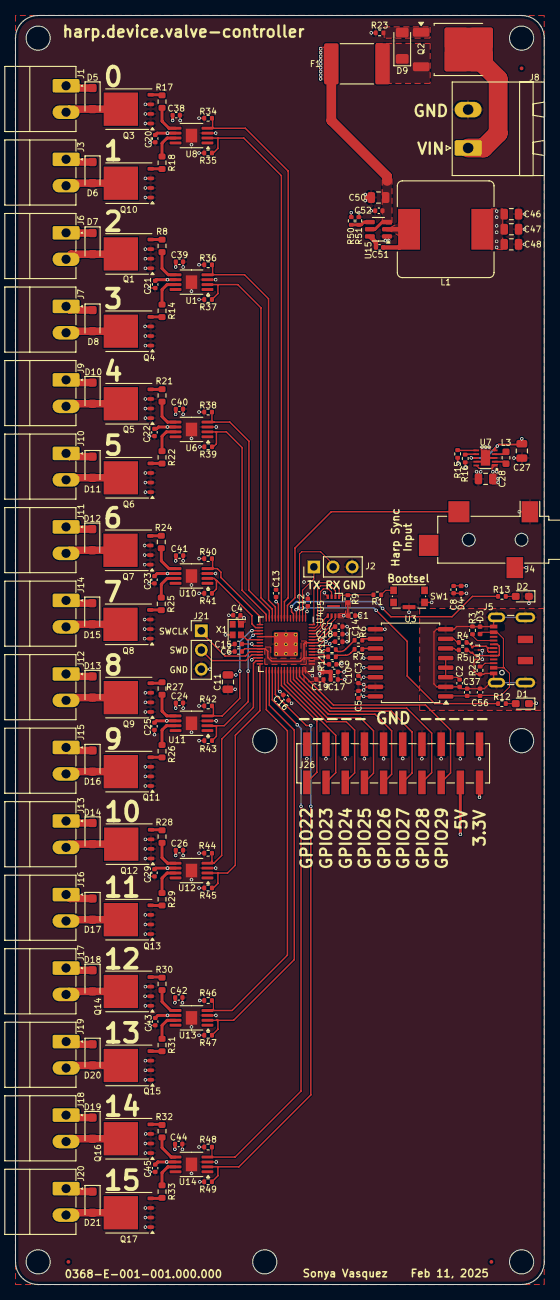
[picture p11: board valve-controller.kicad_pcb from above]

Board: 4 copper layers, 70.0 x 168.0 mm, 177 parts (1 on the bottom side), 119 nets.

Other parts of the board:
R12, R13: 680; R_0402_1005Metric
REF1: OSHW-Logo2_7.3x6mm_SilkScreen

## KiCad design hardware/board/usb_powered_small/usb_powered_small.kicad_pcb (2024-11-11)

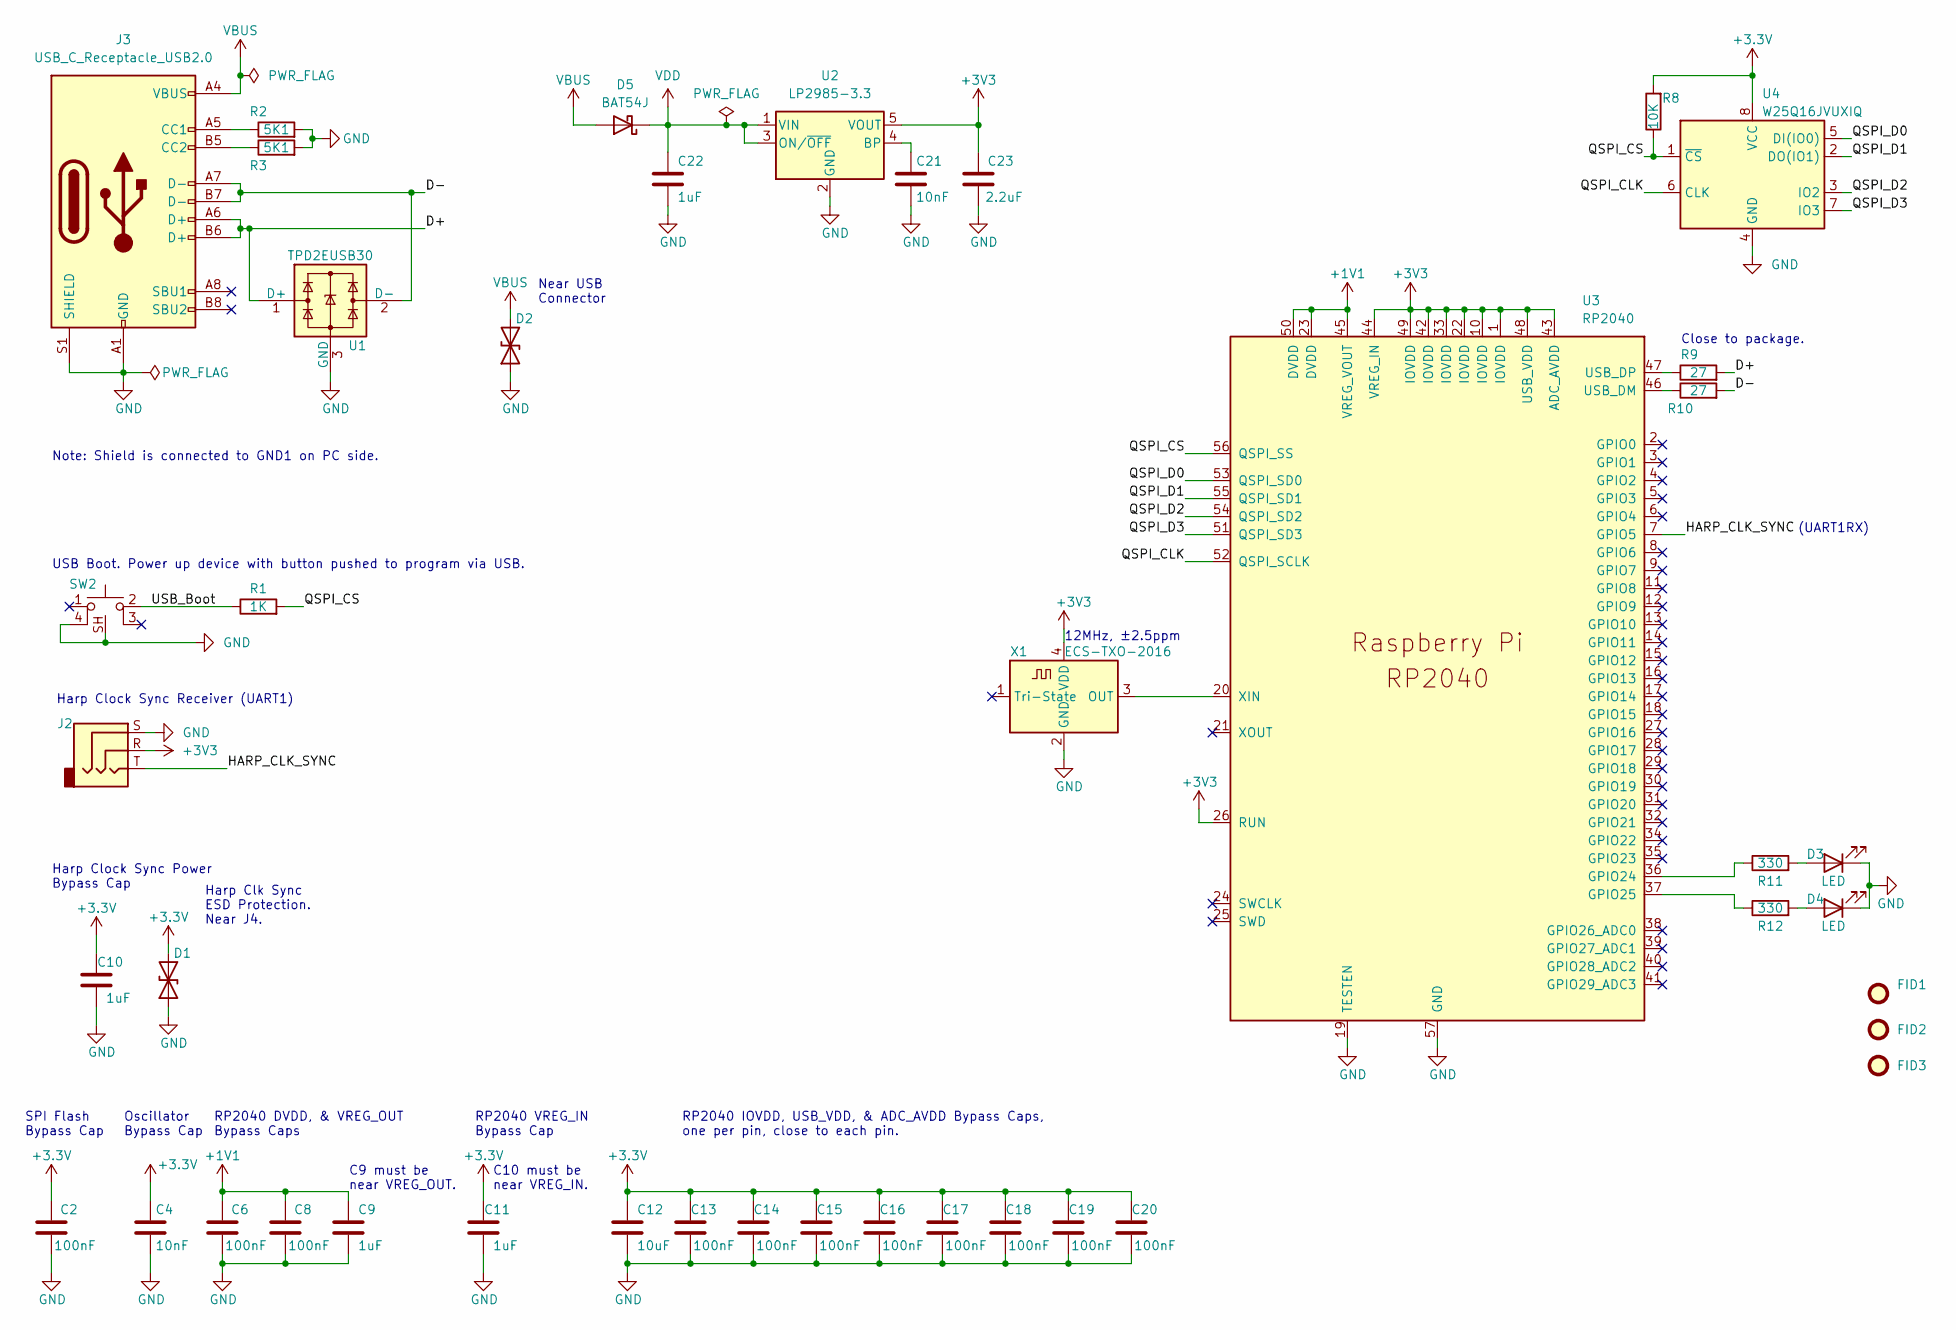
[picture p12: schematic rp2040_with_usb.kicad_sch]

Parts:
C2, C6, C8, C13, C14, C15, C16, C17, C18, C19, C20: 100nF; C_0402_1005Metric; Rated Voltage 16V; Tolerance 10%
C4, C21: 10nF; C_0402_1005Metric; Rated Voltage 25V; Tolerance 2%
C9, C10, C11, C22: 1uF; C_0402_1005Metric; Rated Voltage 35V
C12: 10uF; C_0805_2012Metric; Rated Voltage 25V
C23: 2.2uF; C_0402_1005Metric; Rated Voltage 10V
D1, D2: D_TVS; D_0402_1005Metric
D3, D4: LED; LED_0603_1608Metric_Pad1.05x0.95mm_HandSolder
D5: BAT54J; D_SOD-323F
FID1, FID2, FID3: Fiducial; Fiducial_0.5mm_Mask1mm
J2: AudioJack3; Jack_3.5mm_CUI_SJ-3523-SMT_Horizontal
J3: USB_C_Receptacle_USB2.0; USB_C_Receptacle_JAE_DX07S016JA1R1500
R1: 1K; R_0402_1005Metric; Tolerance 1%
R2, R3: 5K1; R_0402_1005Metric; Tolerance 1%
R8: 10K; R_0402_1005Metric; Tolerance 1%
R9, R10: 27; R_0402_1005Metric; Tolerance 1%
R11, R12: 330; R_0402_1005Metric; Tolerance 0.1%
SW2: SW_Push_1P1T-SH_NO_Vertical_Wuerth_WS-TASV
U1: TPD2EUSB30; Texas_DRT-3
U2: LP2985-3.3; SOT-23-5
U3: RP2040; RP2040-QFN-56
U4: W25Q16JVUXIQ; Winbond-8USON-2x3mm
X1: ECS-TXO-2016; Crystal_SMD_2016-4Pin_2.0x1.6mm; Tolerance ±2.5ppm

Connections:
+1V1: C6.2, C8.2, C9.1, U3.23 (DVDD), U3.45 (VREG_VOUT), U3.50 (DVDD)
/Harp Core RP2040 + USB/D+: J3.A6 (D+), J3.B6 (D+), R9.2, U1.1 (D+)
/Harp Core RP2040 + USB/D-: J3.A7 (D-), J3.B7 (D-), R10.2, U1.2 (D-)
/Harp Core RP2040 + USB/HARP_CLK_SYNC: J2.T, U3.7 (GPIO5)
/Harp Core RP2040 + USB/QSPI_CLK: U3.52 (QSPI_SCLK), U4.6 (CLK)
/Harp Core RP2040 + USB/QSPI_CS: R1.2, R8.1, U3.56 (QSPI_SS), U4.1 (~CS)
/Harp Core RP2040 + USB/QSPI_D0: U3.53 (QSPI_SD0), U4.5 (DI(IO0))
/Harp Core RP2040 + USB/QSPI_D1: U3.55 (QSPI_SD1), U4.2 (DO(IO1))
/Harp Core RP2040 + USB/QSPI_D2: U3.54 (QSPI_SD2), U4.3 (IO2)
/Harp Core RP2040 + USB/QSPI_D3: U3.51 (QSPI_SD3), U4.7 (IO3)
/Harp Core RP2040 + USB/USB_Boot: R1.1, SW2.2
GND: C2.1, C4.2, C6.1, C8.1, C9.2, C10.2, C11.2, C12.2, C13.1, C14.1, C15.1, C16.1, C17.1, C18.1, C19.1, C20.1, C21.2, C22.2, C23.1, D1.1 (A1), D2.1 (A1), D3.1 (K), D4.1 (K), J2.S, J3.A1 (GND), J3.A12 (GND), J3.B1 (GND), J3.B12 (GND), J3.S1 (SHIELD), R2.2, R3.2, SW2.4, SW2.SH, U1.3 (GND), U2.2 (GND), U3.19 (TESTEN), U3.57 (GND), U4.4 (GND), X1.2 (GND)
unnamed: D3.2 (A), R11.2
unnamed: D4.2 (A), R12.2
unnamed: J3.A5 (CC1), R2.1
unnamed: J3.B5 (CC2), R3.1
unnamed: C21.1, U2.4 (BP)
unnamed: R11.1, U3.36 (GPIO24)
unnamed: R12.1, U3.37 (GPIO25)
unnamed: R10.1, U3.46 (USB_DM)
unnamed: R9.1, U3.47 (USB_DP)
unnamed: U3.20 (XIN), X1.3 (OUT)
VBUS: D2.2 (A2), D5.2 (A), J3.A4 (VBUS), J3.A9 (VBUS), J3.B4 (VBUS), J3.B9 (VBUS)
VDD: C22.1, D5.1 (K), U2.1 (VIN), U2.3 (ON/~OFF)

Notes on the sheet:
C10 must be near VREG_IN.
C9 must be near VREG_OUT.
SPI Flash Bypass Cap
Close to package.
Harp Clock Sync Power Bypass Cap
Harp Clock Sync Receiver (UART1)
Oscillator Bypass Cap
RP2040 DVDD, & VREG_OUT Bypass Caps
RP2040 VREG_IN Bypass Cap
USB Boot. Power up device with button pushed to program via USB.
(UART1RX)
RP2040 IOVDD, USB_VDD, & ADC_AVDD Bypass Caps, one per pin, close to each pin.
Near USB Connector
Note: Shield is connected to GND1 on PC side.
12MHz, ±2.5ppm
Harp Clk Sync ESD Protection. Near J4.

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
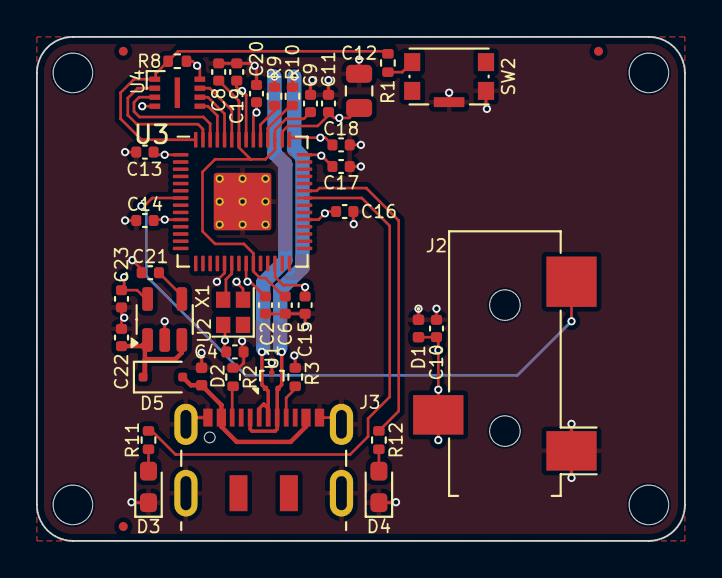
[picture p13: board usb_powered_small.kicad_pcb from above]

Board: 4 copper layers, 36.0 x 28.0 mm, 43 parts (0 on the bottom side), 25 nets.

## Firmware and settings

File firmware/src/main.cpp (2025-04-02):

#include <cstring>
#include <harp_synchronizer.h>
#include <harp_c_app.h>
#include <core_registers.h>
#include <reg_types.h>
#include <config.h>
#include <valve_controller_app.h>
#ifdef DEBUG
    #include <pico/stdlib.h> // for uart printing
    #include <cstdio> // for printf
#endif

// Create Harp App.
HarpCApp& app = HarpCApp::init(HARP_DEVICE_ID,
                               HW_VERSION_MAJOR, HW_VERSION_MINOR,
                               HW_ASSEMBLY_VERSION,
                               HARP_VERSION_MAJOR, HARP_VERSION_MINOR,
                               FW_VERSION_MAJOR, FW_VERSION_MINOR,
                               UNUSED_SERIAL_NUMBER,
                               "valve-controller",
                               (uint8_t*)GIT_HASH,
                               &app_regs, app_reg_specs,
                               reg_handler_fns, APP_REG_COUNT, update_app_state,
                               reset_app);

// Core0 main.
int main()
{
// Init Synchronizer.
    HarpSynchronizer::init(uart1, HARP_SYNC_RX_PIN);
    app.set_synchronizer(&HarpSynchronizer::instance());
#ifdef DEBUG
    stdio_uart_init_full(uart0, 921600, UART_TX_PIN, -1); // use uart1 tx only.
    printf("Hello, from an RP2040!\r\n");
#endif
    reset_app();
    while(true)
        app.run();
}

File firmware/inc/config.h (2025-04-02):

#ifndef CONFIG_H
#define CONFIG_H

#define NUM_VALVES (16)

#define UART_TX_PIN (0)
#define HARP_SYNC_RX_PIN (5)
#define HARP_CORE_LED_PIN (2)

#define VALVE_PIN_BASE (6)
#define GPIO_PIN_BASE (22)

#define VALVES_MASK (0x0000FFFF)
#define GPIOS_MASK (0x000000FF)

#define HARP_DEVICE_ID (1406)
#define HW_VERSION_MAJOR (1)
#define HW_VERSION_MINOR (0)
#define HW_ASSEMBLY_VERSION (0)

#define FW_VERSION_MAJOR (0)
#define FW_VERSION_MINOR (0)
#define FW_VERSION_PATCH (0)

#define UNUSED_SERIAL_NUMBER (0)  // Deprecated in favor of R_UUID

#endif // CONFIG_H

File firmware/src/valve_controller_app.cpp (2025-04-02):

#include <valve_controller_app.h>

app_regs_t app_regs;

uint8_t old_aux_gpio_inputs;


// Creat function aliases for readability.
void (&read_aux_gpio_dir)(uint8_t reg_address) = HarpCore::read_reg_generic;
void (&read_aux_gpio_set)(uint8_t reg_address) = HarpCore::read_reg_generic;
void (&read_aux_gpio_clear)(uint8_t reg_address) = HarpCore::read_reg_generic;

void (&read_aux_gpio_rise_event)(uint8_t reg_address) = HarpCore::read_reg_generic;
void (&read_aux_gpio_fall_event)(uint8_t reg_address) = HarpCore::read_reg_generic;
void (&write_aux_gpio_rise_event)(msg_t& msg) = HarpCore::write_reg_generic;
void (&write_aux_gpio_fall_event)(msg_t& msg) = HarpCore::write_reg_generic;


/// Create Hit-and-Hold Valve Drivers.
/// The underlying PWM peripheral, aka: a PWM Slice, controls two adjacent PWM
/// pins and must be configured with the same settings. This is OK since we are
/// enforcing the same underlying peripheral settings (i.e: frequency) across
/// all Slices.
ValveDriver valve_drivers[NUM_VALVES]
{{VALVE_PIN_BASE},
 {VALVE_PIN_BASE + 1},
 {VALVE_PIN_BASE + 2},
 {VALVE_PIN_BASE + 3},
 {VALVE_PIN_BASE + 4},
 {VALVE_PIN_BASE + 5},
 {VALVE_PIN_BASE + 6},
 {VALVE_PIN_BASE + 7},
 {VALVE_PIN_BASE + 8},
 {VALVE_PIN_BASE + 9},
 {VALVE_PIN_BASE + 10},
 {VALVE_PIN_BASE + 11},
 {VALVE_PIN_BASE + 12},
 {VALVE_PIN_BASE + 13},
 {VALVE_PIN_BASE + 14},
 {VALVE_PIN_BASE + 15}};

// Define "specs" per-register
RegSpecs app_reg_specs[APP_REG_COUNT]
{
    {(uint8_t*)&app_regs.ValvesState, sizeof(app_regs.ValvesState), U16},
    {(uint8_t*)&app_regs.ValvesSet, sizeof(app_regs.ValvesSet), U16},
    {(uint8_t*)&app_regs.ValvesClear, sizeof(app_regs.ValvesClear), U16},

    {(uint8_t*)&app_regs.ValveConfigs[0], sizeof(ValveConfig), U8},
    {(uint8_t*)&app_regs.ValveConfigs[1], sizeof(ValveConfig), U8},
    {(uint8_t*)&app_regs.ValveConfigs[2], sizeof(ValveConfig), U8},
    {(uint8_t*)&app_regs.ValveConfigs[3], sizeof(ValveConfig), U8},
    {(uint8_t*)&app_regs.ValveConfigs[4], sizeof(ValveConfig), U8},
    {(uint8_t*)&app_regs.ValveConfigs[5], sizeof(ValveConfig), U8},
    {(uint8_t*)&app_regs.ValveConfigs[6], sizeof(ValveConfig), U8},
    {(uint8_t*)&app_regs.ValveConfigs[7], sizeof(ValveConfig), U8},
    {(uint8_t*)&app_regs.ValveConfigs[8], sizeof(ValveConfig), U8},
    {(uint8_t*)&app_regs.ValveConfigs[9], sizeof(ValveConfig), U8},
    {(uint8_t*)&app_regs.ValveConfigs[10], sizeof(ValveConfig), U8},
    {(uint8_t*)&app_regs.ValveConfigs[11], sizeof(ValveConfig), U8},
    {(uint8_t*)&app_regs.ValveConfigs[12], sizeof(ValveConfig), U8},
    {(uint8_t*)&app_regs.ValveConfigs[13], sizeof(ValveConfig), U8},
    {(uint8_t*)&app_regs.ValveConfigs[14], sizeof(ValveConfig), U8},
    {(uint8_t*)&app_regs.ValveConfigs[15], sizeof(ValveConfig), U8},

    {(uint8_t*)&app_regs.AuxGPIODir, sizeof(app_regs.AuxGPIODir), U8},
    {(uint8_t*)&app_regs.AuxGPIOState, sizeof(app_regs.AuxGPIOState), U8},
    {(uint8_t*)&app_regs.AuxGPIOSet, sizeof(app_regs.AuxGPIOSet), U8},
    {(uint8_t*)&app_regs.AuxGPIOClear, sizeof(app_regs.AuxGPIOClear), U8},

    {(uint8_t*)&app_regs.AuxGPIOInputRiseEvent, sizeof(app_regs.AuxGPIOInputRiseEvent), U8},
    {(uint8_t*)&app_regs.AuxGPIOInputFallEvent, sizeof(app_regs.AuxGPIOInputFallEvent), U8},
    {(uint8_t*)&app_regs.AuxGPIORisingInputs, sizeof(app_regs.AuxGPIORisingInputs), U8},
    {(uint8_t*)&app_regs.AuxGPIOFallingInputs, sizeof(app_regs.AuxGPIOFallingInputs), U8},
    // More specs here if we add additional registers.
};

RegFnPair reg_handler_fns[APP_REG_COUNT]
{
    {read_valves_state, write_valves_state},
    {read_valves_set, write_valves_set},
    {read_valves_clear, write_valves_clear},

    {read_any_valve_config, write_any_valve_config}, // valve 0
    {read_any_valve_config, write_any_valve_config}, // valve 1
    {read_any_valve_config, write_any_valve_config}, // ...
    {read_any_valve_config, write_any_valve_config},
    {read_any_valve_config, write_any_valve_config},
    {read_any_valve_config, write_any_valve_config},
    {read_any_valve_config, write_any_valve_config},
    {read_any_valve_config, write_any_valve_config},
    {read_any_valve_config, write_any_valve_config},
    {read_any_valve_config, write_any_valve_config},
    {read_any_valve_config, write_any_valve_config},
    {read_any_valve_config, write_any_valve_config},
    {read_any_valve_config, write_any_valve_config},
    {read_any_valve_config, write_any_valve_config},
    {read_any_valve_config, write_any_valve_config},
    {read_any_valve_config, write_any_valve_config}, // valve 15

    {read_aux_gpio_dir, write_aux_gpio_dir},
    {read_aux_gpio_state, write_aux_gpio_state},
    {read_aux_gpio_set, write_aux_gpio_set},
    {read_aux_gpio_clear, write_aux_gpio_clear},

    {read_aux_gpio_rise_event, write_aux_gpio_rise_event},
    {read_aux_gpio_fall_event, write_aux_gpio_fall_event},
};


void read_valves_state(uint8_t reg_address)
{
    for (size_t valve_index = 0; valve_index < NUM_VALVES; ++valve_index)
    {
        app_regs.ValvesState = 0;
        if (valve_drivers[valve_index].is_energized())
            app_regs.ValvesState |= (typeof(app_regs.ValvesState))(1) << valve_index;
    }
    if (!HarpCore::is_muted())
        HarpCore::send_harp_reply(READ, reg_address);
}

void write_valves_state(msg_t& msg)
{
    HarpCore::copy_msg_payload_to_register(msg);
    for (size_t valve_index = 0; valve_index < NUM_VALVES; ++valve_index)
    {
        if ((app_regs.ValvesState >> valve_index) & (typeof(app_regs.ValvesState))(1))
            valve_drivers[valve_index].energize();
        else
            valve_drivers[valve_index].deenergize();
    }
    // Reply with the actual value that we wrote.
    if (!HarpCore::is_muted())
        HarpCore::send_harp_reply(WRITE, msg.header.address);
}

void read_valves_set(uint8_t reg_address)
{
    // Return the most recently set value.
    if (!HarpCore::is_muted())
        HarpCore::send_harp_reply(READ, reg_address);
}

void write_valves_set(msg_t& msg)
{
    HarpCore::copy_msg_payload_to_register(msg);
    for (size_t valve_index = 0; valve_index < NUM_VALVES; ++valve_index)
    {
        if ((app_regs.ValvesSet >> valve_index) & (typeof(app_regs.ValvesSet))(1))
            valve_drivers[valve_index].energize();
    }
    if (!HarpCore::is_muted())
        HarpCore::send_harp_reply(WRITE, msg.header.address);
}

void read_valves_clear(uint8_t reg_address)
{
    // Return the most recently cleared value.
    if (!HarpCore::is_muted())
        HarpCore::send_harp_reply(READ, reg_address);
}
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

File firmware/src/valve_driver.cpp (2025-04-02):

#include <valve_driver.h>


ValveDriver::ValveDriver(uint8_t pwm_pin)
:pwm_{pwm_pin}, hit_output_{1.0}, hold_output_{1.0}, hit_duration_us_{0},
 energize_queued_{false}, deenergize_queued_{false}
{
    reset();
}

ValveDriver::~ValveDriver()
{
    pwm_.disable_output();
}

void ValveDriver::set_normalized_hit_output(float output)
{
    hit_output_ = output;
    // Reapply the frequency change if we are in the right state.
    if (state_ == HIT)
        pwm_.set_duty_cycle(hit_output_);
}

void ValveDriver::set_normalized_hold_output(float output)
{
    hold_output_ = output;
    // Reapply the frequency change if we are in the right state.
    if (state_ == HOLD)
        pwm_.set_duty_cycle(hold_output_);
}

void ValveDriver::set_hit_duration_us(uint32_t hit_duration_us)
{
    hit_duration_us_ = hit_duration_us;
}

float ValveDriver::set_pwm_frequency_hz(float hz)
{
    return pwm_.set_frequency(hz);
}

void ValveDriver::reset_fsm()
{
    hit_start_time_us_ = 0;
    state_ = DEENERGIZED;
}

void ValveDriver::reset()
{
    // Default to "hold" settings that are identical to "hit" settings.
    hit_output_ = 1.0f;
    hold_output_ = 1.0f;
    hit_duration_us_ = 0;
    set_pwm_frequency_hz(DEFAULT_PWM_FREQUENCY_HZ);
    reset_fsm();
    deenergize();
    pwm_.enable_output();
}

void ValveDriver::energize()
{
    energize_queued_ = true;
    update_fsm();
}

void ValveDriver::deenergize()
{
    deenergize_queued_ = true;
    update_fsm();
}

void ValveDriver::update_fsm()
{
    uint32_t curr_time_us = time_us_32();
    // Handle next-state logic (based on inputs and current state).
    State next_state{state_};
    // Start with state transition logic that applies to all states.
    if (energize_queued_)
        next_state = HIT;
    else if (deenergize_queued_)
        next_state = DEENERGIZED;
    else // Handle state-based state transition logic.
    {
        switch (state_)
        {
            case HIT:
                if ((curr_time_us - hit_start_time_us_) >= hit_duration_us_)
                    next_state = HOLD;
                break;
            case HOLD:
                break;
            case DEENERGIZED:
                break;
            default:
                break;
        }
    }
    // Handle output logic based on inputs current state, and next state.
    if (energize_queued_ && (next_state == HIT))
    {
        hit_start_time_us_ = curr_time_us;
        pwm_.set_duty_cycle(hit_output_);
    }
    else if ((state_ != HOLD) && (next_state == HOLD))
        pwm_.set_duty_cycle(hold_output_);
    else if (next_state == DEENERGIZED)
        pwm_.set_duty_cycle(0);

    // Clear flags
    energize_queued_ = false;
    deenergize_queued_ = false;

    // Apply state transition.
    state_ = next_state;
}

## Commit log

2025-02-04 draft board layout
    [board_power.kicad_sch, isolated_usb_rp2040.kicad_sch, valve-controller.kicad_pcb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]
2025-02-06 route pcb
    [board_power.kicad_sch, isolated_usb_rp2040.kicad_sch, sma_ttl_out.kicad_sch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]
2025-02-07 update pcb power supply
    [board_power.kicad_sch, isolated_usb_rp2040.kicad_sch, valve-controller.kicad_pcb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]
2025-02-07 update bom
    [board_power.kicad_sch, valve-controller.kicad_pcb, valve_control.kicad_sch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]
2025-02-09 prep hw initial release
    [board_power.kicad_sch, isolated_usb_rp2040.kicad_sch, valve-controller.kicad_pcb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]
2025-02-11 add device.yaml and gpio pinout pic
2025-02-18 update silkscreen w/ gpio descriptions
    [valve-controller.kicad_pcb]
2025-02-19 draft hit and hold valve driver
2025-02-20 draft get/set valve config
2025-02-20 draft harp Reg access to config valve hit/hold settings
2025-02-20 attach bulk valve control registers to ValveDrivers
2025-02-20 tick ValveDriver FSMs in app update fn
2025-02-28 add mini clamp connector aux gpio breakout
    [harp.breakout.mini-clamp.kicad_pcb, harp.breakout.mini-clamp.kicad_sch]
2025-03-01 route breakout board layout partially
    [harp.breakout.mini-clamp.kicad_pcb, harp.breakout.mini-clamp.kicad_sch]
2025-03-03 update breakout
    [harp.breakout.mini-clamp.kicad_pcb, harp.breakout.mini-clamp.kicad_sch]
2025-03-07 update breakout board silk
    [harp.breakout.mini-clamp.kicad_pcb]
2025-03-10 update mini clamp breakout bom
    [harp.breakout.mini-clamp.kicad_sch]
2025-03-18 tease pwm class into its own repo
2025-09-09 disambiguate LEDs in schematic
